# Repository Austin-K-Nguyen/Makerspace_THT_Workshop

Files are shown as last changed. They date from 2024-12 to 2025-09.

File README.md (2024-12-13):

<p align="center">
  <image src="https://github.com/Austin-K-Nguyen/Makerspace_THT_Workshop/blob/main/Images/makerspace_logo.png">
</p>
<h1 align="center">Makerspace THT Workshop Dino</h1>

<p align="center">
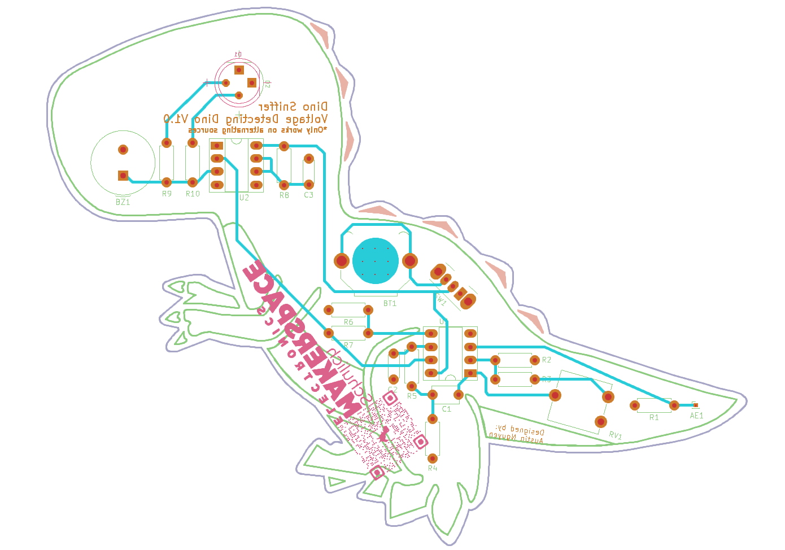
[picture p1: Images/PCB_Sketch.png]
  
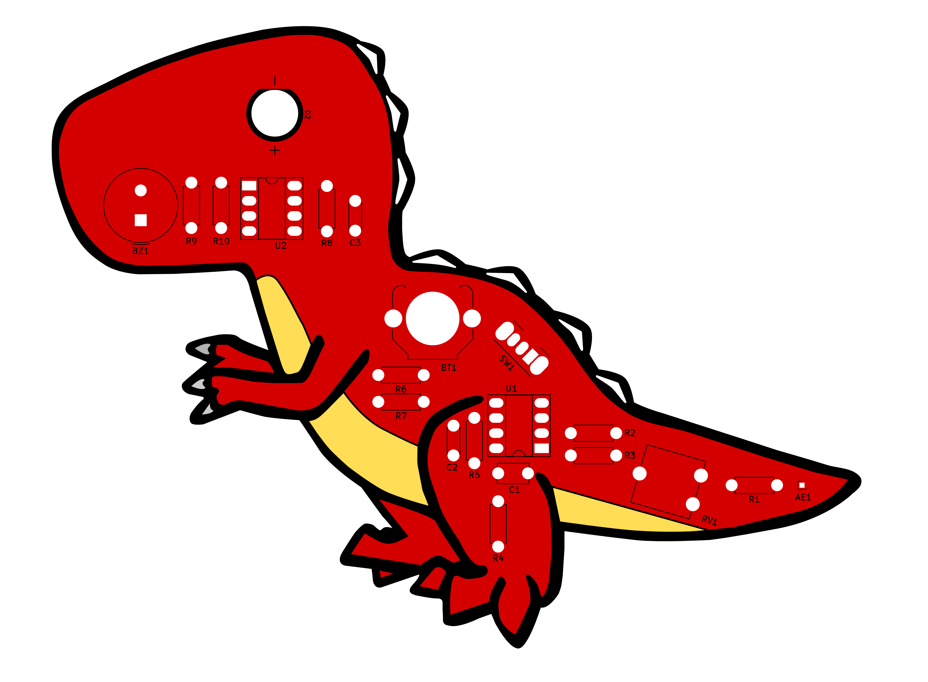
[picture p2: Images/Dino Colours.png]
   
</p>
<h2 align="left">About</h2>

Introducing! The newest soldering workshop developed for the Schulich School of Engineering Makermultipliex and Zetta, the new Voltage Sniffing Rex!

Created as a cool educational toy and NOT as a replacement or alternative to a REAL electrical tester, the Voltage Sniffing Rex can detect and react to live wires containing AC voltages.

This prototype aims to introduce beginners to basic through-hole soldering techniques and safety in a new and interactive way. The contents of this repo should provide 
all the files necessary to produce these dinos for yourself.

For more information about equipment, trainings and classes offered within the Makermultiplex visit https://schulich.libguides.com/m2z/.
And for more cool dino themed project kits, checkout the Flex-E Rex Soldering Kit here https://github.com/Lee-F-Evans/Flex-E-Rex-Soldering-Kit

<h2 align="left">Gathering Parts</h2>

To create the kits you'll need to order some PCBS, gather all the nessassary parts listed in the BOM excel sheet, and grab some basic soldering tools.

<h2 align="left">PCB Fabrication</h2>

The repo above should include both KiCad project files should you feel like viewing or modifying them, and also ready made gerbers and image reference files (TBA) that can be used directly for PCB manufacturing.

The PCB's were order from PCBWay as they provide full UV colour printing onto PCB's using simple image files and some extra silkscren work when designing the PCB. 

* Of note as of writing this, other manufacturers such as JLC PCB do also provide full colour printing, but require you to use their own deisgn software for it to work, as such unless this changes I reccomended using PCBWay as your main board manufacturer.

<h2 align="left">Parts</h2>

The provided bill of materials or BOM provided above, details all the nessassary parts required for this kit. The BOM along with listing parts, also links Digi-Key part listings should you wish to order them from them, though ordering the parts from any vendor should also work.
<h4 align="left">Part Substitutions</h4>

* A note on the 555 timer ic, the LMC555 timer spcificed in the BOM does have a standard pinout so feel free to change the chip out for any numerious different versions of the 555 chip, though it MUST be able to operate at atleast 3V preferably below and share the same standard pinout.

* A note on the LM358 op-amp ic, again this 8-pin duel op-amp ic has a standard pinout, so feel free to change out the chip for any number of duel op-amp, 8-pin, standard pinout ics that operate at preferably below 3v.

<h2 align="left">Tools</h2>

You'll only need the basic tools to solder for this this kit including,
* Soldering Iron
* Lead-Free Solder
* Flush Cutters / Wire Cutters

And Thats it!

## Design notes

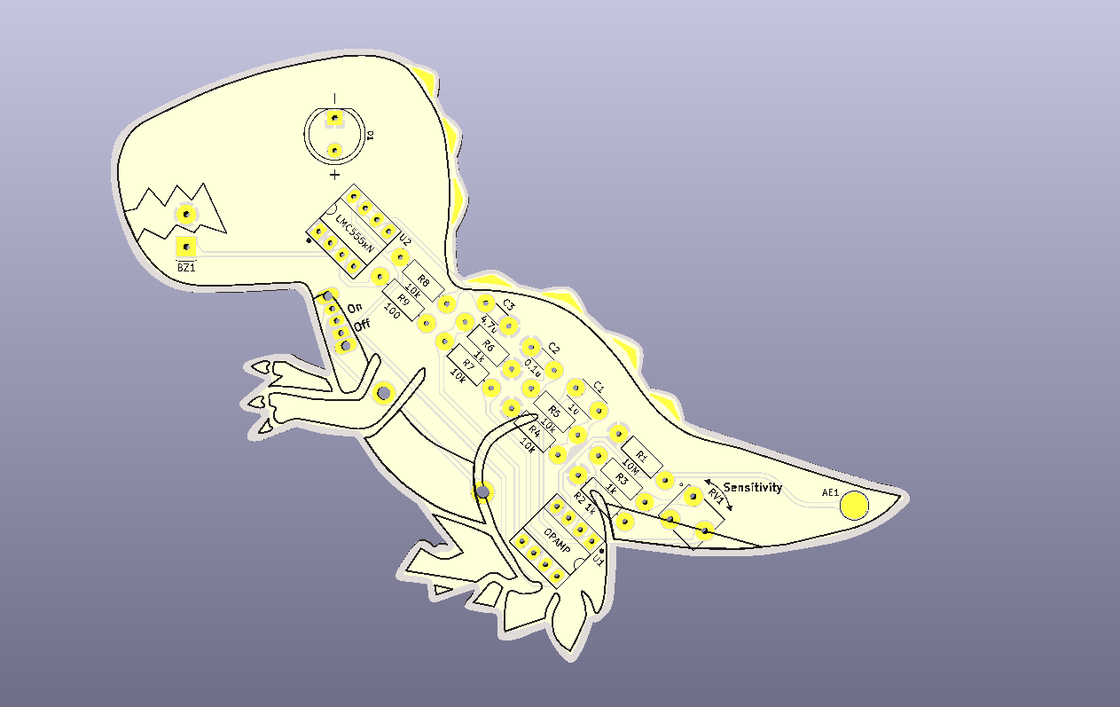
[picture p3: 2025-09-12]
Gerbs/3D_Reference.png

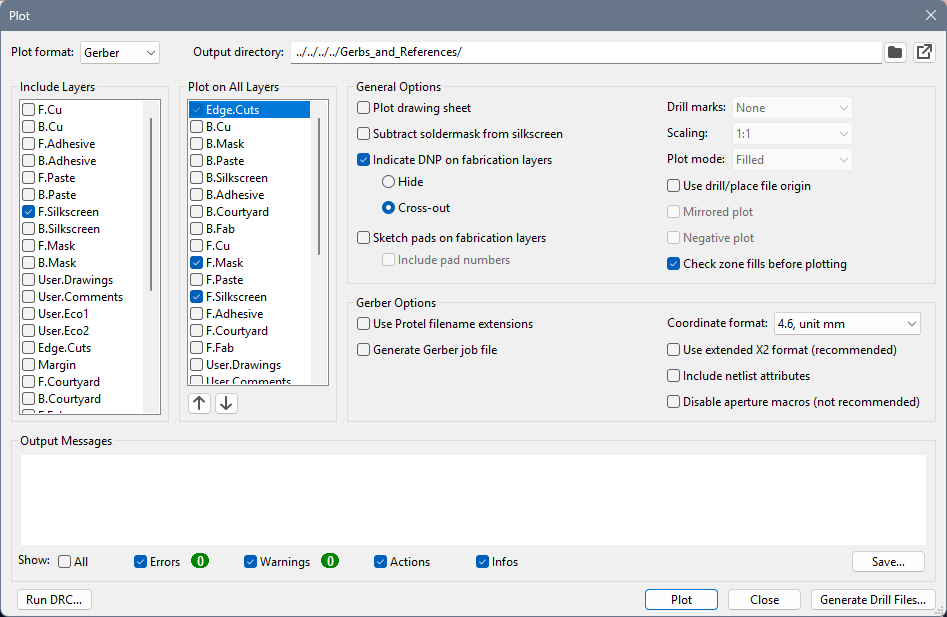
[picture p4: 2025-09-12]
References/Recommended_SVG_Settings.png

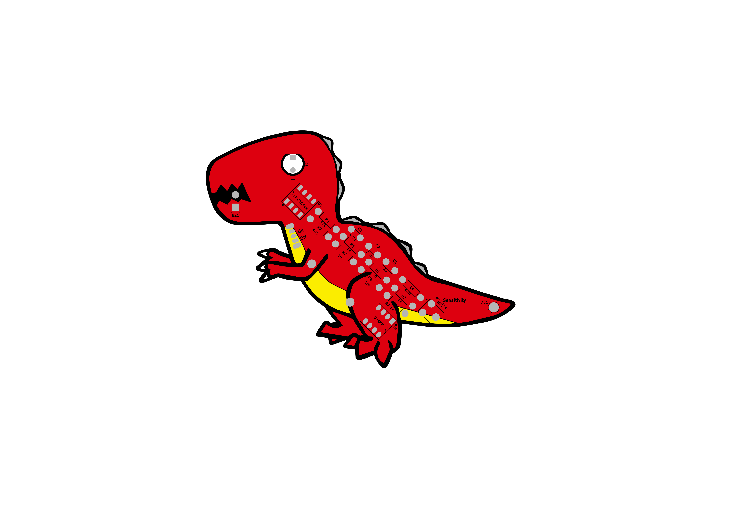
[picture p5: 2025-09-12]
Gerbs/Colour_Reference.png

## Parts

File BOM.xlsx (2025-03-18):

New THT Workshop BOM
Part | Description | Number | Cost | Total Cost | Link | Total Sum = | $6.59 | Total Part Count = | 22
Timer IC | LMC555CN | 1 | $1.46 | $1.46 | https://www.digikey.ca/en/products/detail/texas-instruments/LMC555CN-NOPB/32623 | *For single unit
Buzzer | PS1240P02BT 3V Piezo Buzzer | 1 | $0.56 | $0.56 | https://www.digikey.ca/en/products/detail/tdk-corporation/PS1240P02BT/935924
Red LEDs | C503B-RAN-CZ0C0AA2 5mm Red LEDs | 2 | $0.18 | $0.36 | https://www.digikey.ca/en/products/detail/cree-led/C503B-RAN-CZ0C0AA2/6561762
Potentiometers | 601030 TRIMMER 10K OHM 0.1W PC PIN TOP | 1 | $0.31 | $0.31 | https://www.digikey.ca/en/products/detail/kyocera-avx/601030/10491403
Switch | OS102011MA1QN1 SPDT Switch | 1 | $0.71 | $0.71 | https://www.digikey.ca/en/products/detail/c-k/OS102011MA1QN1/1981430
Battery Holder | BATT RETAINER COIN 20MM PC PIN | 1 | $0.55 | $0.55 | https://www.digikey.ca/en/products/detail/mpd-memory-protection-devices/BK-913/2329371
OP Amp IC | LM358P | 1 | $0.23 | $0.23 | https://www.digikey.ca/en/products/detail/texas-instruments/LM358P/277042
IC Socket | 1-2199298-2 CONN IC DIP SOCKET 8POS TIN | 2 | $0.22 | $0.44 | https://www.digikey.ca/en/products/detail/te-connectivity-amp-connectors/1-2199298-2/5022039
10k Resistors | MFR-25FRF52-10K 10 kOhms ±1% 0.25W, 1/4W Through Hole Resistor Axial Metal Film | 5 | $0.10 | $0.50 | https://www.digikey.ca/en/products/detail/stackpole-electronics-inc/RNF14FTD10K0/1706596
10M Resistors | CF14JT10M0 RES 10M OHM 5% 1/4W AXIAL | 1 | $0.10 | $0.10 | https://www.digikey.ca/en/products/detail/stackpole-electronics-inc/CF14JT10M0/1741267
1k Resistors | RNF14FTD1K00 RES 1K OHM 1% 1/4W AXIAL | 2 | $0.10 | $0.20 | https://www.digikey.ca/en/products/detail/stackpole-electronics-inc/RNF14FTD1K00/1706678
100 Resistors | MFR-25FRF52-100R 100 Ohms ±1% 0.25W, 1/4W Through Hole Resistor Axial Metal Film | 1 | $0.10 | $0.10 | https://www.digikey.ca/en/products/detail/yageo/MFR-25FRF52-100R/14795
0.1u Capacitors | K104K10X7RF5UH5 0.1 µF ±10% 50V Ceramic Capacitor X7R Radial | 1 | $0.18 | $0.18 | https://www.digikey.ca/en/products/detail/vishay-beyschlag-draloric-bc-components/K104K10X7RF5UH5/2356754
1u Capacitors | RDER71H105K2M1H03A CAP CER 1UF 50V X7R RADIAL | 1 | $0.48 | $0.48 | https://www.digikey.ca/en/products/detail/murata-electronics/RDER71H105K2M1H03A/4771301
4.7u Capacitor | FG28X5R1E475KRT06 CAP CER 4.7UF 25V X5R RADIAL | 1 | $0.41 | $0.41 | https://www.digikey.ca/en/products/detail/tdk-corporation/FG28X5R1E475KRT06/5803191

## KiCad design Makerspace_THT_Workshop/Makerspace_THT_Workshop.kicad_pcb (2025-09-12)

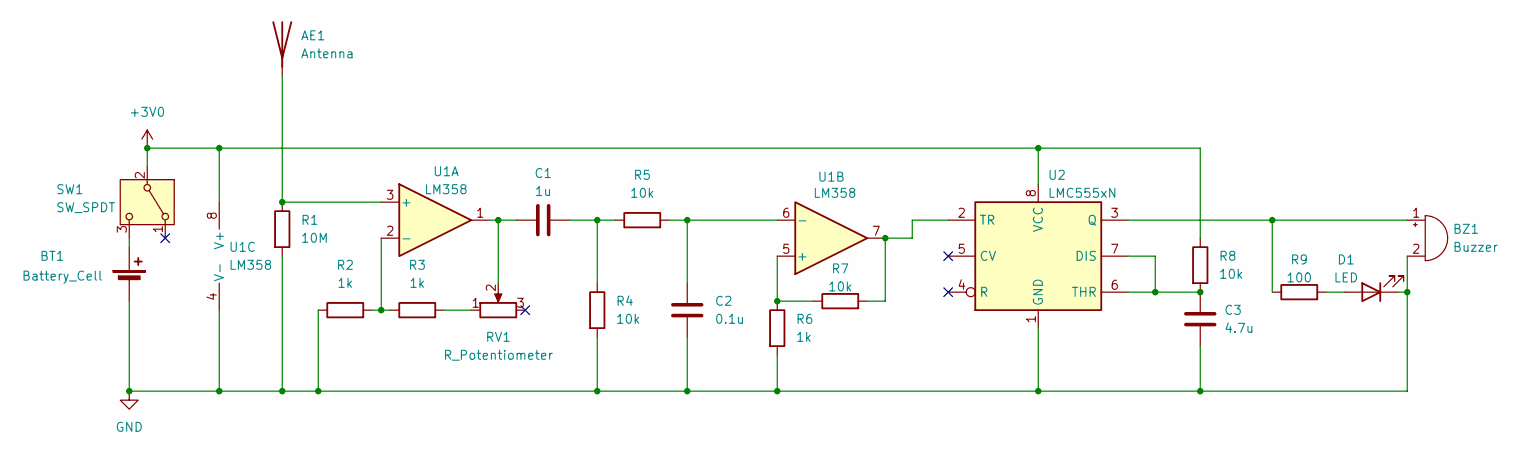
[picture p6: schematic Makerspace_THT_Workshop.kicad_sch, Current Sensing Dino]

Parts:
AE1: Antenna; TestPoint_Pad_D4.0mm
BT1: Battery_Cell; BK-913_MPD
BZ1: Buzzer; Buzzer_TDK_PS1240P02BT_D12.2mm_H6.5mm
C1: 1u; C_Disc_D5.1mm_W3.2mm_P5.00mm
C2: 0.1u; C_Disc_D4.3mm_W1.9mm_P5.00mm
C3: 4.7u; C_Disc_D4.3mm_W1.9mm_P5.00mm
D1: LED; LED_D5.0mm_5.0mm_Pitch
R1: 10M; R_Axial_DIN0207_L6.3mm_D2.5mm_P10.16mm_Horizontal
R2, R3, R6: 1k; R_Axial_DIN0207_L6.3mm_D2.5mm_P10.16mm_Horizontal
R4, R5, R7, R8: 10k; R_Axial_DIN0207_L6.3mm_D2.5mm_P10.16mm_Horizontal
R9: 100; R_Axial_DIN0207_L6.3mm_D2.5mm_P10.16mm_Horizontal
RV1: R_Potentiometer; 601030_AVX
SW1: SW_SPDT; SW_Slide_SPDT_Angled_CK_OS102011MA1Q
U1: LM358; DIP-8_W7.62mm_Socket_LongPads
U2: LMC555xN; DIP-8_W7.62mm_Socket_LongPads

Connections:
+3V0: R8.1, SW1.2 (B), U1.8 (V+), U2.8 (VCC)
GND: BT1.2 (-), BZ1.2 (-), C2.1, C3.2, D1.1 (K), R1.2, R2.1, R4.2, R6.2, U1.4 (V-), U2.1 (GND)
unnamed: AE1.1 (A), R1.1, U1.3 (+)
unnamed: BT1.1 (+), SW1.3 (C)
unnamed: BZ1.1 (+), R9.1, U2.3 (Q)
unnamed: C1.1, RV1.2, U1.1
unnamed: C1.2, R4.1, R5.1
unnamed: D1.2 (A), R9.2
unnamed: R3.2, RV1.1
unnamed: R2.2, R3.1, U1.2 (-)
unnamed: R6.1, R7.1, U1.5 (+)
unnamed: C2.2, R5.2, U1.6 (-)
unnamed: C3.1, R8.2, U2.6 (THR), U2.7 (DIS)
unnamed: R7.2, U1.7, U2.2 (TR)

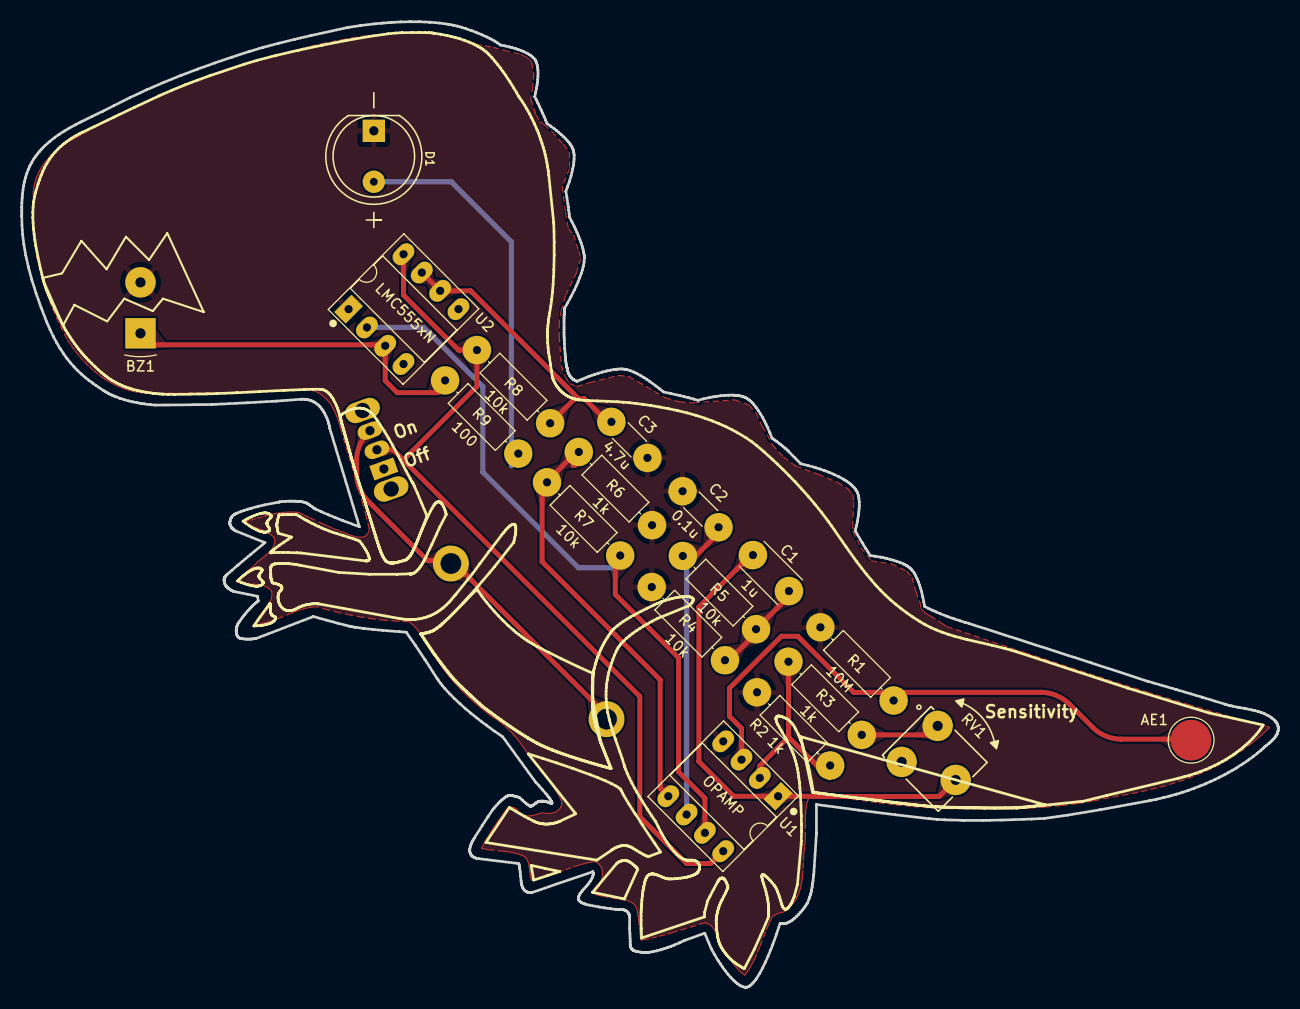
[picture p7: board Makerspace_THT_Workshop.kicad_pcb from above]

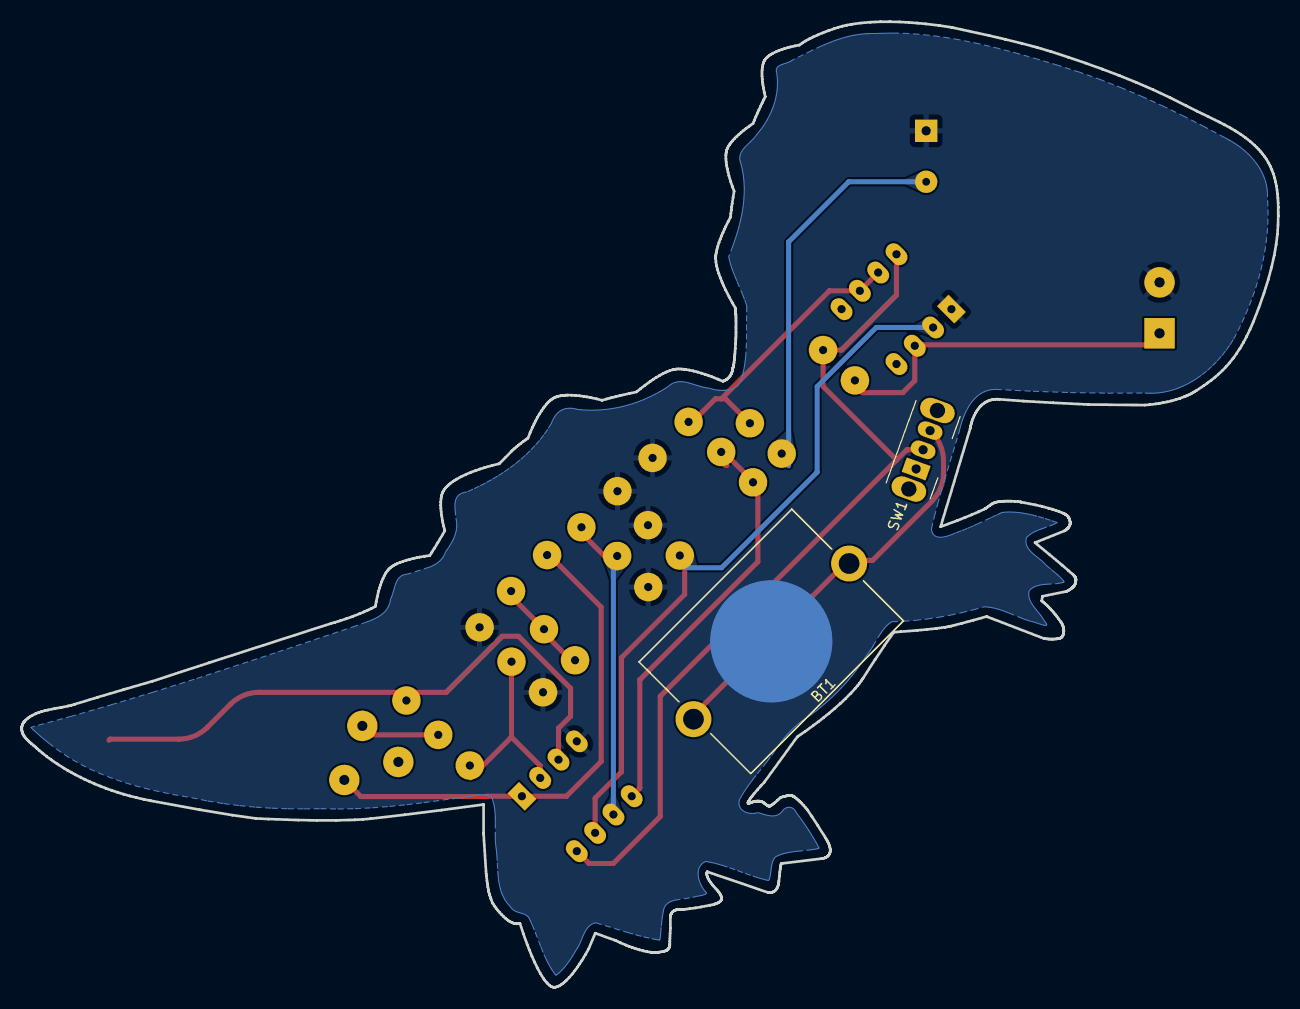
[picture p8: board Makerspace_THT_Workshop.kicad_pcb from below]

Board: 2 copper layers, 123.3 x 94.8 mm, 20 parts (2 on the bottom side), 14 nets.

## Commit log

2024-12-09 Intial commit, includes all initial pcb and schem diagrams
    [Makerspace_THT_Workshop.kicad_pcb, Makerspace_THT_Workshop.kicad_sch]
2024-12-10 Updated PCB with testpoints and text
    [BOM.xlsx, Makerspace_THT_Workshop.kicad_pcb]
2024-12-12 Added some more detail to pcb and more assets
    [Makerspace_THT_Workshop.kicad_pcb]
2024-12-13 Added gerb files
    [Makerspace_THT_Workshop-B_Cu.gbr, Makerspace_THT_Workshop-B_Mask.gbr, Makerspace_THT_Workshop-B_Paste.gbr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]
2025-02-19 Updated the board to fix alot of stuff
    [BOM.xlsx, Makerspace_THT_Workshop.kicad_pcb, Makerspace_THT_Workshop.kicad_sch]
2025-03-07 New Version of the PCB layout
    [Makerspace_THT_Workshop.kicad_pcb, Makerspace_THT_Workshop.kicad_sch]
2025-03-18 Minor Layout Changes
    [Makerspace_THT_Workshop.kicad_pcb]
2025-09-12 Updated PCB layout, vectors, and updated references
    [Makerspace_THT_Workshop-B_Cu.gbr, Makerspace_THT_Workshop-B_Mask.gbr, Makerspace_THT_Workshop-B_Paste.gbr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]
